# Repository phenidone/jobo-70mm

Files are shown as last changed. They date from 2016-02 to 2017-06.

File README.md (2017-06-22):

# jobo-70mm

This is a 3D-printable adapter to develop 70mm film in Jobo 2502 spirals.

## Purpose

70mm film is a little wider than 120 film, so it doesn't fit in a normal film spiral.  This adapter 
is a sleeve that is to be inserted into the middle of a Jobo 2502 spiral (as used in the 2xxx tanks),
thereby making the spiral wider and allowing 70mm film to be inserted into a 2502 spiral and developed
in a 2xxx tank.

## Limitations

It is not compatible with Jobo 1xxx spirals/tanks, or with Paterson spirals.

While you can buy dedicated 70mm developing spirals and tanks, but they are very expensive.  Many of us
have basic Jobo gear, and this allows small quantities of 70mm film to be developed.

The adapter should be printed in ABS with 100% infill, and (for FDM) in the orientation shown, i.e. a vertical cylinder.
Assuming you want to develop multiple spirals of film in a single batch, you will need to print multiple adapters.

## Usage

A 2502 spiral can hold about 1.6m of film - enough for a 135-36 roll, two 120 rolls or a 220 roll.
Therefore, you cannot expose 20 feet of 70mm and expect to stuff it all into a single spiral and develop
it in a single batch.  You need to find some way of marking the film off into 220-lengths and cutting the film
at the right points when unloading it from your canister into the spiral

I do this by putting little tabs of sticky tape onto the film, through the gate on the back.  First, expose 
a suitable quantity, e.g. 20 frames of 6x7.  Advance one frame, pull the darkslide by a couple centimetres and
stick some tape to the film, then advance again.  Expose another 20 frames, and repeat.

When applying the tape, use about 4cm, and fold the adhesive faces together so that it sticks together with
about 5mm of fresh adhesive exposed.  This gives a non-adhesive flap that can poke out from the film and be
felt easily in the dark without getting fingerprints all over the film.

When unloading the film, you can feel for the tape loop and cut it at that point, in the middle of the wasted frame.

The adapter makes the spirals wider, therefore fewer fit into a single tank.  One spiral will still fit into the
single-spiral tank, but only two expanded spirals will fit into the three-spiral tank.  The same fluid-minimum
levels apply.

## License

This hardware design is (C) 2014 William Brodie-Tyrrell and is licensed under the CERN OHL; see cern_ohl_v_1_2.pdf

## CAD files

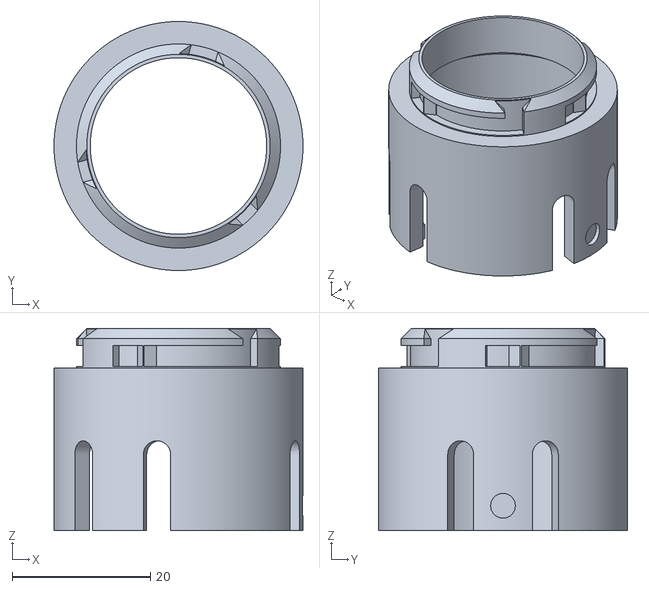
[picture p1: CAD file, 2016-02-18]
jobo-adapter.stl
36.0 x 36.0 x 29.2

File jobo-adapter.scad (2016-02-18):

use <pieslice.scad>

$fs=0.1;
$fn=200;

epsilon=0.05;

/// the female/outer part of a Jobo 2502 shaft connection
/// datum is tooth centre, bottom face is at -1.25.
module jobo_female(height=15, slotdepth=11) {

	// stress-relief notches surrounding tooth (outer cyl)
	relief=[4, slotdepth];
	
	// outer cylinder diameters
	diam=[30.5, 36];
	R=0.5*diam;
	thickness=R[1]-R[0];
	middle=0.5*(R[0]+R[1]);
	// angle between notches per pair
	notchsep=40;
	// notch angles
	// notches=[0, 120, 240, notchsep, 120+notchsep, 240+notchsep];
	notches=[0+0.5*notchsep, 120+0.5*notchsep, 240+0.5*notchsep, -0.5*notchsep, 120-0.5*notchsep, 240-0.5*notchsep];
	// tooth angles
	// teeth=[0.5*notchsep, 120+0.5*notchsep, 240+0.5*notchsep];
	teeth=[0, 120, 240];
	// tooth size for locking; goes on inside of outer cylinder
	tooth=[1.5, 3.5, 2.5];
    toothwidth=[3.5, 2.5, 2.5];

    marker=[1.8, 1.5];

	translate([0, 0, -0.5*tooth[2]]){

		difference() {
			// main body
			translate([0, 0, height/2]) cylinder(h=height, r1=R[1], r2=R[1], center=true);

			// subtract inner cylinder
			translate([0, 0, height/2]) cylinder(h=height+epsilon, r1=R[0], r2=R[0], center=true);

			// subtract stress-relief notches
			for(a=notches){
				rotate([0, 0, a]){
					translate([middle, 0, relief[1]/2-0.5])
						cube([thickness+1, relief[0], relief[1]+1], center=true);
					translate([middle, 0, relief[1]])
						rotate([0, 90, 0])
                        cylinder(h=thickness+1, r=0.5*relief[0], center=true, $fn=36);
				}
			}

            // subtract marker-circle
            translate([R[1], 0, 2*marker[0]]) rotate([0, 90, 0]) 
                cylinder(h=marker[1], r=marker[0], center=true, $fn=20);
		}

        // add teeth to bottom edge
		for(i=[0:2]){
			rotate([0, 0, teeth[i]]){
				translate([R[0], 0, 0.5*tooth[2]+epsilon])
					cube([2*tooth[0], toothwidth[i], tooth[2]], center=true);
			}
		}
	}

}

/// the male/inner part of a Jobo 2502 shaft connection, one slot only
/// datum is at zero, in order to mesh with female.  Top surface at Z=4.
module jobo_male(height=10, limitdepth=true, tightretain=false) {
	// inner cylinder diameters
	diam=[25.5, 29.5];
	R=0.5*diam;
    middle=0.5*(R[0]+R[1]);
    thickness=R[1]-R[0];
	
	// z values
    taper=1.5;
	ztop=4;
	ztaper=ztop-taper;
	ztopnotch=1.55;
	zbotnotch=-1.55;
    znotchwidth=ztopnotch-zbotnotch;
    znotchmid=0.5*(ztopnotch+zbotnotch);
    znotchlen=6.5;
    zcentre=ztop-0.5*(height);
    zover=height+epsilon;

    // notch spacing & sizing
    notches=[0, 120, 240];
    notchwidth=[4, 3, 3];
    notchdepth=1.4;
    notchlength=85;

    // retaining teeth
    retainoff=tightretain ? notchlength-20 : 35;
    retains=[-retainoff:120:240-retainoff];

	difference() {
        union() {
            // main cylinder
            translate([0, 0, ztaper-0.5*height+0.5*taper])
                cylinder(h=height-taper, r1=R[1], r2=R[1], center=true);

            // tapered top
            translate([0, 0, ztaper+0.5*taper])
                cylinder(h=taper, r1=R[1], r2=R[1]-taper, center=true);
        }
        // subtract centre core
		translate([0, 0, ztop-0.5*height]) cylinder(h=height+epsilon, r1=R[0], r2=R[0], center=true);

        // subtract all the notch structures
        intersection() {
            // form a notch sleeve
            difference() {                               
                translate([0, 0, zcentre]) cylinder(h=zover, r=R[1]+epsilon, center=true);
                translate([0, 0, zcentre]) cylinder(h=zover+epsilon, r=R[1]-notchdepth, center=true);

                // also subtract retaining-bumps from the possible sleeve
                for(a=retains){
                    rotate([0, 0, a]) {
                        translate([R[1]-notchdepth, 0, znotchmid])
                            rotate([0, 0, 45]) cube([1.5*notchdepth, 1.5*notchdepth, znotchwidth+1], center=true);
                    }
                }
            }

            // decide which bits of the sleeve to keep, i.e. where slots/notches will be
            union() {
                // for(a=notches){
                for(i=[0:3]){
                    rotate([0, 0, notches[i]]){
                        if(limitdepth){
                            // vertical notch going down as far as top slot
                            translate([middle, 0, zbotnotch+0.5*znotchlen])
                                cube([thickness+epsilon, notchwidth[i], znotchlen], center=true);
                        }
                        else{
                            // full-depth vertical notch
                            translate([middle, 0, zcentre])
                                cube([thickness+epsilon, notchwidth[i], zover], center=true);
                        }

                        // tapers on entry to vertical notch
                        translate([middle, 0, ztop]) rotate([45, 0, 0]) 
                            cube([thickness, 0.707*notchwidth[i]+1.414*taper, 0.707*notchwidth[i]+1.414*taper], center=true);

                        // top slot
                        translate([0, 0, zbotnotch])
                            pie_slice(height=znotchwidth, r=R[1]+3, amax=0, amin=-notchlength, aseg=10);
                    }                    
                }
            }
        }
	}
}

/// a spacer to go between two spiral halves, making them 9mm further apart
/// this allows the loading of 70mm film in a 120/220 spiral.  Note that this
/// connects to the second row on the male spiral, which is 16mm below the first row,
/// which is why we have a 16+9=25mm datum offset between the two interfaces.
module jobo_spacer() {

    expand=24;

    mheight=8.5;
    join_top=expand-1.75;
    join_bot=expand-mheight+4;
    join_mid=0.5*(join_top+join_bot);
    join_len=join_top-join_bot;
    join_R=[14, 16];

    echo(join_len);

    difference() {
        union() {
            // male connector at top, rotated so that once locked in, the spiral's
            // angular relationship is unchanged.
            rotate([0, 0, 75]) translate([0, 0, expand]) 
                jobo_male(height=mheight, tightretain=true);

            // joining ring
            difference() {
                translate([0, 0, join_mid]) cylinder(h=join_len, r=join_R[1], center=true);
                translate([0, 0, join_mid]) cylinder(h=join_len+epsilon, r=join_R[0], center=true);
            }
        }

        // subtract out a chamfer to ease the build and provide more clearance
        translate([0, 0, join_bot-epsilon]) 
            cylinder(h=4, r1=16, r2=10);
    }


    // female connector at bottom
    jobo_female(height=expand-0.5);
}

jobo_spacer();  

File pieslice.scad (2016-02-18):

/// a partial (in angle) cylinder.  Outside edge is not clean.
/// used for masking off segments of a circular extrusion.
module pie_slice(height, r, amin=0, amax=90, aseg=5, center=false){
    for(a=[amin:aseg:amax-aseg]){

        linear_extrude(height=height, convexity=10, center=center)
            polygon(points=[ [0, 0], 
                             [r*cos((a == amin) ? a : (a-0.05*aseg)), r*sin((a == amin) ? a : (a-0.05*aseg))], 
                             [r*cos(a+aseg), r*sin(a+aseg)] ],
                    paths=[ [0, 1, 2] ]);
    }
}

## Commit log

2016-02-18 copied 70mm adapter from svn
    [jobo-adapter-rev_A.stl, jobo-adapter-rev_B.stl, jobo-adapter-rev_C.stl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]
2017-06-22 added CERN license, deleted old versions, updated README
    [jobo-adapter-rev_A.stl, jobo-adapter-rev_B.stl, jobo-adapter-rev_C.stl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]
